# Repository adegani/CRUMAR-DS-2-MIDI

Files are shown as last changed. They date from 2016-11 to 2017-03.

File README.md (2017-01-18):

# CRUMAR-DS-2-MIDI
Add MIDI features to Crumar DS-2 Analog synth using Arduino or bare ATMega328 (with Arduino Bootloader)

This work is published under GNU/GPL.

**NOTE:** This is a WORK IN PROGRESS! Use with caution!

## Abstract
The Crumar DS-2 is a vintage made in Italy analog synth. Unfortunately, it comes without a MIDI IN/OUT capabilityes.
The goal of this project is to add the MIDI port to this wonderful peace of gear by simply substitute the original keyboard decoder board (P-431 on the DS-2 schematics) whit a new one that add MIDI capabilities.

In this repository you can find the Arduino sketch and the schematics of the DS-2_MIDI board and the connection diagram of the Crumar P-431 board.

The DS-2_MIDI board comes in two fashions:

### DS-2 MIDI IN
This simple board provides only MIDI IN to the DS-2. The schematics comes with two microcontroller footprints: one for the Arduino Nano and one for the bare ATMega328 chip.

What you **can do** with this board?
* Receive MIDI NOTE ON/OFF messages

**NOTE:** with this board, the DS-2 keyboard will be **disabled**.

In order to use this variant, please make sure to comment the line
```C
#define DS2_FULL_VARIANT
```
in **config.h**, and refer to the schematic and board *P-431_MIDI_IN_NANO* or *P-431_MIDI_IN_BARE* depending on if you use Arduino Nano or ATMega328 bare chip.

### DS-2 MIDI FULL (under development)
This advanced board provides MIDI IN and OUT to the DS-2. The schematics comes with two microcontroller footprints: one for the Arduino Nano and one for the bare ATMega328 chip.

What you **can do** with this board?
* Receive MIDI NOTE ON/OFF messages
* Send MIDI NOTE ON/OFF from DS-2 keyboard
* Send and Receive MIDI pitch shift messages (TO BE IMPLEMENTED)

**NOTE:** with this board, the DS-2 keyboard are still **usable**.

In order to use this variant, please UNcomment the line
```C
#define DS2_FULL_VARIANT
```
in **config.h**, and refer to the schematic and board *P-431_MIDI_FULL*.

## DISCLAIMER
This is not a commercial work. USE IT AT YOUR OWN RISK. I'm not responsible of any damage to your Arduino / DS-2 or your person.

### Uploading DS-2 sketch using Arduino
1. Upload Arduino ISP sketch to your Arduino
2. Open DS-2 Sketch
3. Select board -> Arduino Duemilanove or Diecimila with processor ATmega328
4. Select Programmer -> Arduino as ISP 
5. Press Upload using programmer (Ctrl+Shift+U)

If you receive a signature error, modify /home/axel/Software/arduino/hardware/tools/avr/etc/avrdude.conf, section m328p, modify the signature 0x1e 0x95 0x0F with 0x1e 0x95 0x14

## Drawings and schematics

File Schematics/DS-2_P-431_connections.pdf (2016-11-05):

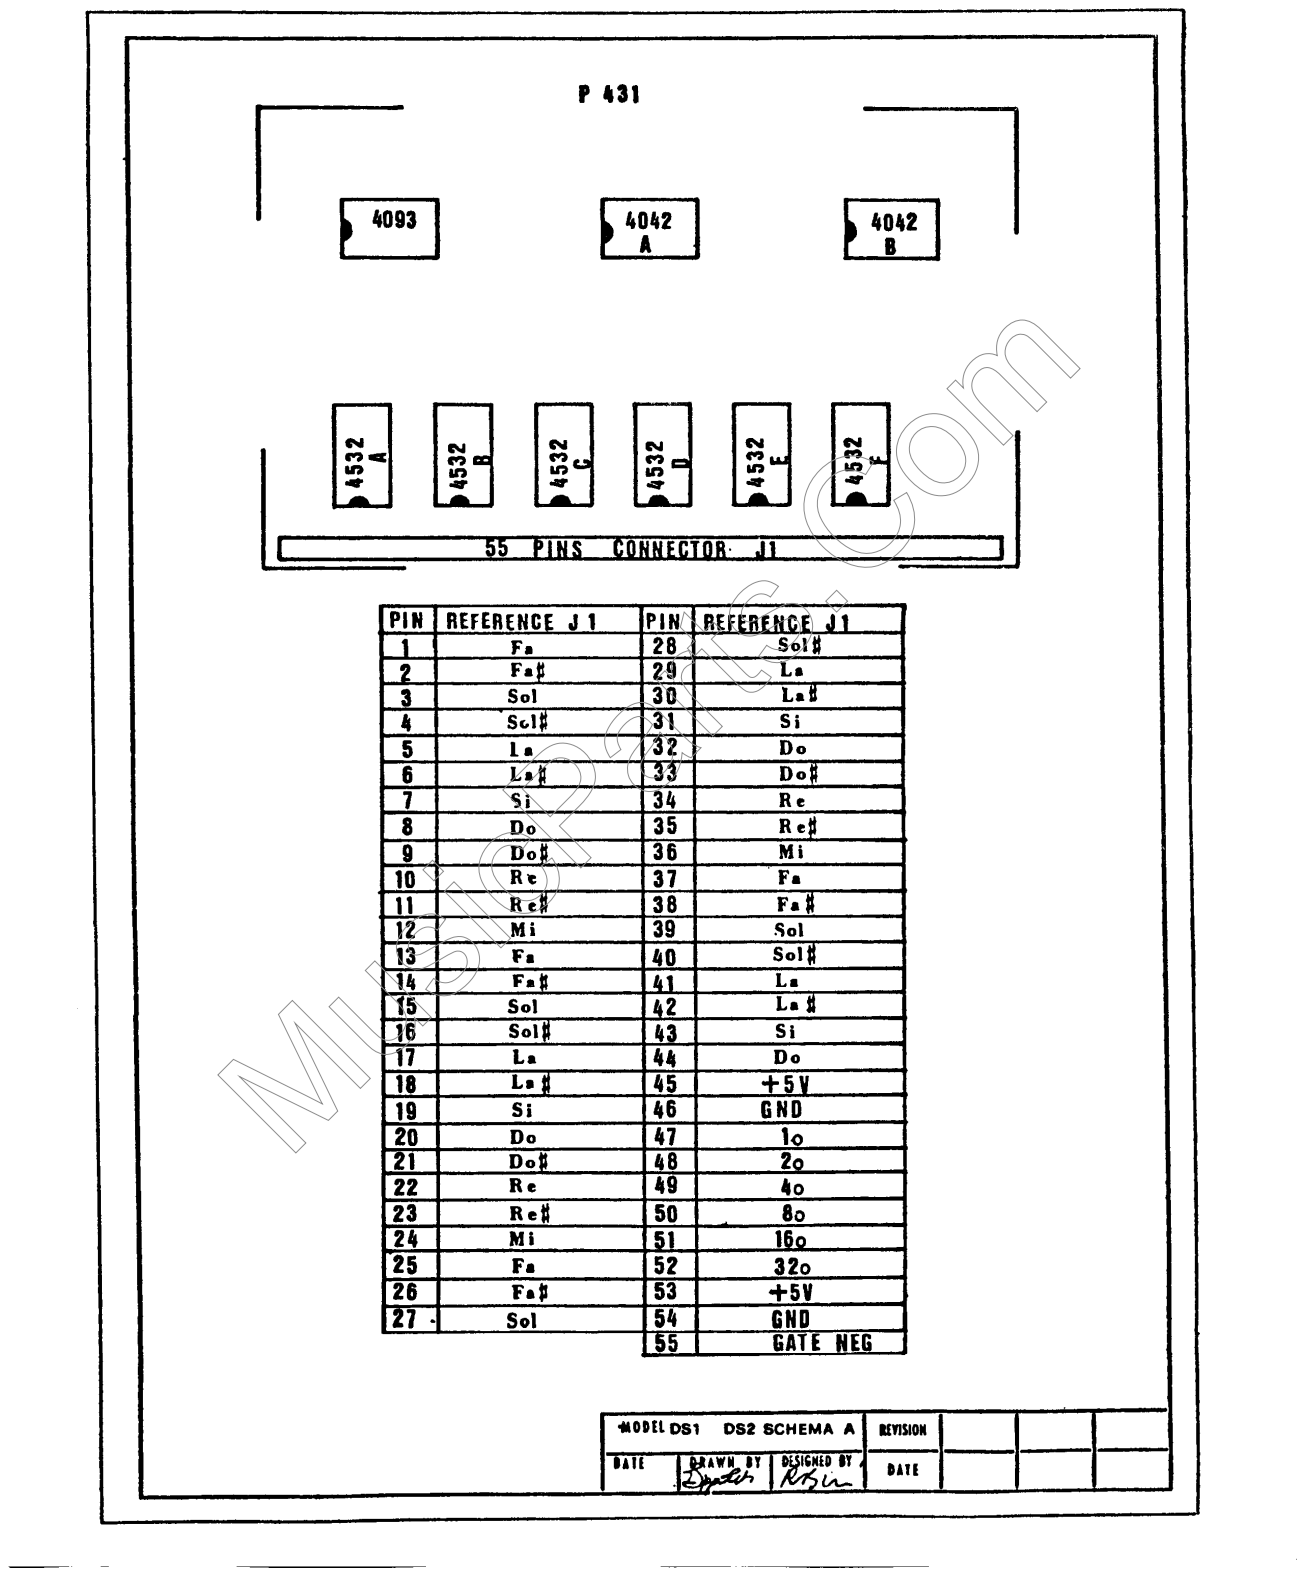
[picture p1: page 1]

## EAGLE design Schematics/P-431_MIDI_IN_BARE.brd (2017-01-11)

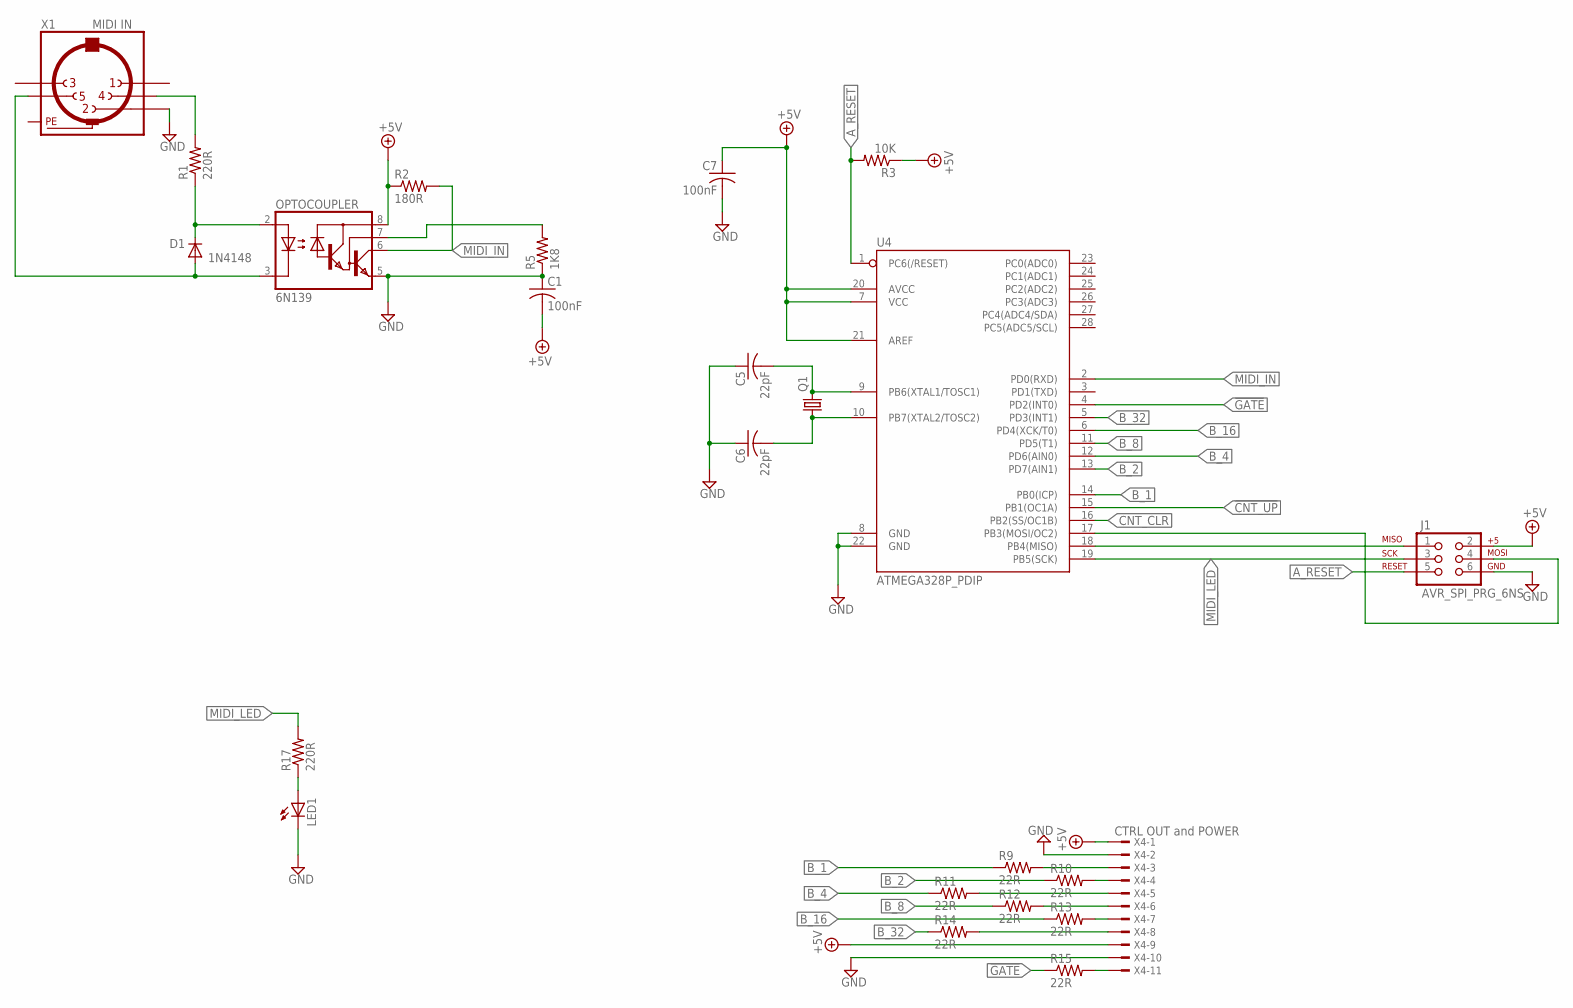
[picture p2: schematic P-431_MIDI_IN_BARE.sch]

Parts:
C1, C7: 100nF; C050-025X075
C5, C6: 22pF; C050-025X075
D1: 1N4148; DIODE-1N4148
J1: AVR_SPI_PRG_6NS; 2X3-NS
LED1: LED5MM
OPTOCOUPLER: 6N139; DIL08; MPN 6N138
Q1: CRYSTALHC49S; HC49/S
R1, R17: 220R; 0207/7
R2: 180R; 0207/7
R3: 10K; 0207/7
R5: 1K8; 0207/7
R9, R10, R11, R12, R13, R14, R15: 22R; 0207/7
U4: ATMEGA328P_PDIP; DIL28-3
X1: MIDI IN; MAB5SH
X4: CTRL OUT and POWER; TSW-111-02-S-S-RA

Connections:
!CNT_UP: U4.15 (PB1(OC1A))
!GATE: R15.1, U4.4 (PD2(INT0))
+5V: C1.2, C7.1, J1.2, OPTOCOUPLER.8 (VCC), R2.1, R3.1, U4.7 (VCC), U4.20 (AVCC), U4.21 (AREF), X4.1, X4.9
A_RESET: J1.5, R3.2, U4.1 (PC6(/RESET))
B_1: R9.1, U4.14 (PB0(ICP))
B_2: R10.1, U4.13 (PD7(AIN1))
B_4: R11.1, U4.12 (PD6(AIN0))
B_8: R12.1, U4.11 (PD5(T1))
B_16: R13.1, U4.6 (PD4(XCK/T0))
B_32: R14.1, U4.5 (PD3(INT1))
CNT_CLR: U4.16 (PB2(SS/OC1B))
GND: C1.1, C5.1, C6.1, C7.2, J1.6, LED1.K (C), OPTOCOUPLER.5 (GND), R5.1, U4.8 (GND), U4.22 (GND), X1.2, X4.2, X4.10
MIDI_IN: OPTOCOUPLER.6 (VO), R2.2, U4.2 (PD0(RXD))
MIDI_LED: J1.3, R17.2, U4.19 (PB5(SCK))
unnamed: D1.A, OPTOCOUPLER.3 (C), X1.5
unnamed: D1.C, OPTOCOUPLER.2 (A), R1.1
unnamed: R1.2, X1.4
unnamed: OPTOCOUPLER.7 (VB), R5.2
unnamed: LED1.A, R17.1
unnamed: R9.2, X4.3
unnamed: R10.2, X4.4
unnamed: R11.2, X4.5
unnamed: R12.2, X4.6
unnamed: R13.2, X4.7
unnamed: R14.2, X4.8
unnamed: R15.2, X4.11
unnamed: C5.2, Q1.2, U4.9 (PB6(XTAL1/TOSC1))
unnamed: C6.2, Q1.1, U4.10 (PB7(XTAL2/TOSC2))
PE: X1.PE, X1.PE@ (PE)
POT_DI: J1.1, U4.18 (PB4(MISO))
POT_SCK: J1.4, U4.17 (PB3(MOSI/OC2))

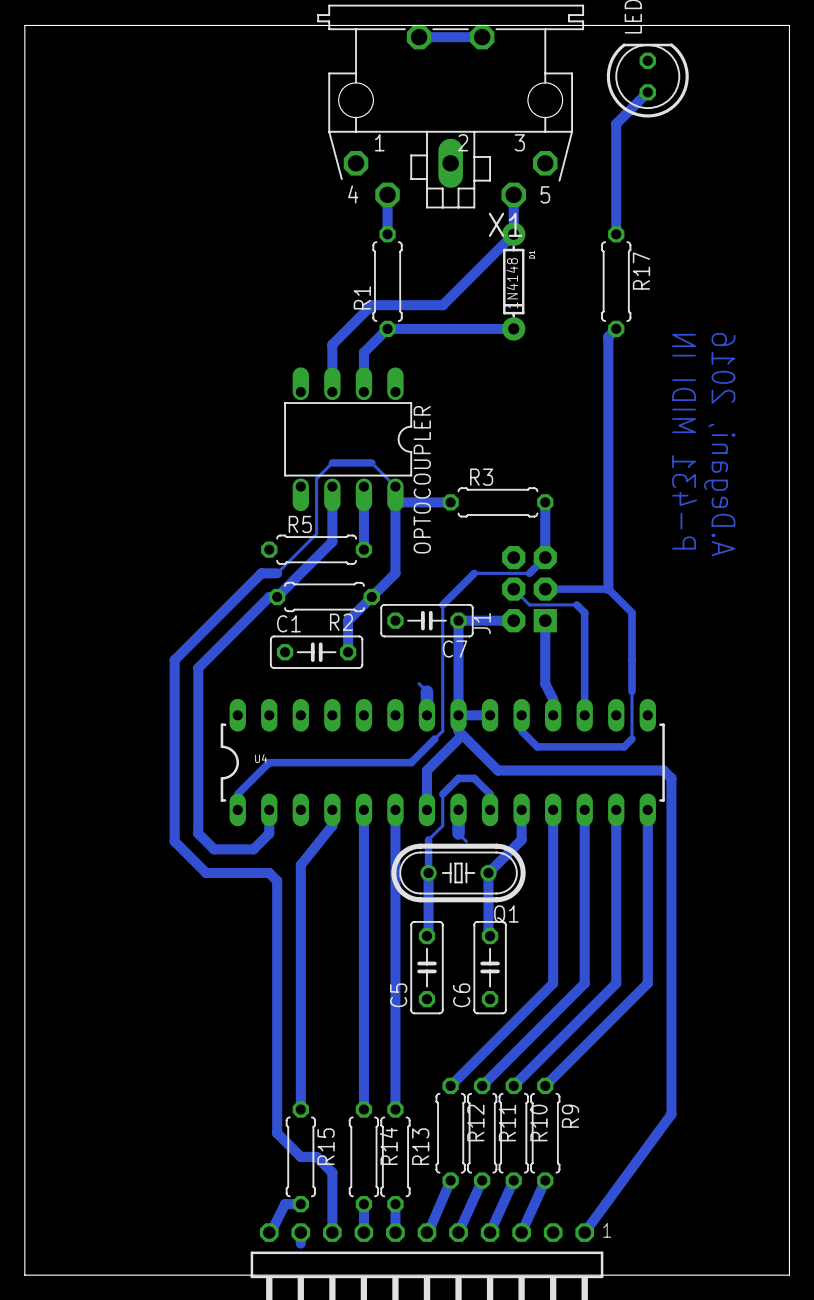
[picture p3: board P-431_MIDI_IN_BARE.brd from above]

Board: 2 copper layers, 61.6 x 100.6 mm, 24 parts (0 on the bottom side), 29 nets.

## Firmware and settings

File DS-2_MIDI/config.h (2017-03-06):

/* config.h
 *  Config and Arduino pin names
 *  Author: Alessio Degani, 2016 <alessio.degani@gmail.com>
 */

#ifndef DS2_CONFIG_H
#define DS2_CONFIG_H

// General Config
//#define DS2_FULL_VARIANT // Uncomment to use FULL variant instead of NANO

// Note priority [LAST|HIGHER|LOWER]
#define PLAY_MODE_MIDI LAST

// Gate mode [GATE_SINGLE|GATE_RETRIGGER]
#define DEFAULT_GATE_MODE GATE_SINGLE

#define NOTE_TRANSPOSE_SEMITONE 0

// Default MIDI channel
#define DEFAULT_MIDI_CH 0

// Control Change for P431-MIDI
#define DS2_PLAY_MODE      0x66
#define DS2_GATE_MODE      0x67
#define DS2_SET_CHANNEL    0x68
#define DS2_HOLD_NOTE      0x69
#define DS2_ARP_MODE       0x6A
#define DS2_TRANSPOSE_SEMI 0x6B

// Configure the ATMega328 pin names

// OUTPUTS to CRUMAR
#define DS2_GATE_NEG  2
#define DS2_32o       3
#define DS2_16o       4
#define DS2_8o        5
#define DS2_4o        6
#define DS2_2o        7
#define DS2_1o        8

// DS-2 MIDI NOTE range
#define DS2_LOWER_NOTE  41
#define DS2_HIGHER_NOTE 84

// MIDI ports and LED
#define MIDI_LED      13
#define MIDI_OUT      0
#define MIDI_IN       1

// ----- NOT USED IN DS-2 MIDI IN only VERSION -----

// COUNTER
#define COUNT_UP_NEG  9
#define COUNT_CLR     10

// DIGIPOT --> OUT (pitch shifter)
#define POT_SCK       11
#define POT_DI        12

// ANALOG POT --> READ (pitch shifter)
#define PS_POT1       A5
#define PS_POT2       A4
#define PS_POT3       A3

// MUX READ (INPUT from CRUMAR keyboard)
#define K0            A0
#define K1            A1
#define K2            A2

#endif // DS2_CONFIG_H

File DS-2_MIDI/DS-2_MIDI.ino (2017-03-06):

/* DS-2 MIDI IN NANO
 *  Add MIDI input capabilities to CRUMAR DS-2
 *  Author: Alessio Degani, 2016 <alessio.degani@gmail.com>
 */

#include "config.h"
#include "noteList.h"
#include "midiDefs.h"
#include "midiFSM.h"

midiFSM_t midiFSM;

enum gate_mode_e { GATE_SINGLE, GATE_RETRIGGER };
gate_mode_e gate_mode = DEFAULT_GATE_MODE;

byte midiChannel = DEFAULT_MIDI_CH;

MidiNoteList<16> midiNotes;

byte lastNote;
byte midiByte;

// Note transposition
int transposeSemitone = NOTE_TRANSPOSE_SEMITONE;

// MIDI led activity, led_status is for pesistence of the led, otherwise, the led will stay on too few
bool          midi_led_status         = 0;
unsigned int  midi_led_duration_loops = 3;
unsigned int  midi_led_timer          = 0;

void playNote( byte note, byte velocity ){

  // TODO: forse questo ciclo adesso si può eliminare
  // A note off -> close the gate 
  if ( (velocity == 0) || (note < DS2_LOWER_NOTE) || (note > DS2_HIGHER_NOTE) ) {
    digitalWrite( DS2_GATE_NEG, HIGH );
    return;
  }

  note = note + transposeSemitone;

  if (( note >= DS2_LOWER_NOTE ) && ( note <= DS2_HIGHER_NOTE )) {
    note = note - DS2_LOWER_NOTE;

    if ( (gate_mode == GATE_RETRIGGER) && (lastNote != note) ) {
      digitalWrite( DS2_GATE_NEG, HIGH );
    }

    ( (note & 32) == 32 ) ? digitalWrite(DS2_32o, HIGH): digitalWrite(DS2_32o, LOW);
    ( (note & 16) == 16 ) ? digitalWrite(DS2_16o, HIGH): digitalWrite(DS2_16o, LOW);
    ( (note & 8)  == 8 )  ? digitalWrite(DS2_8o, HIGH): digitalWrite(DS2_8o, LOW);
    ( (note & 4)  == 4 )  ? digitalWrite(DS2_4o, HIGH): digitalWrite(DS2_4o, LOW);
    ( (note & 2)  == 2 )  ? digitalWrite(DS2_2o, HIGH): digitalWrite(DS2_2o, LOW);
    ( (note & 1)  == 1 )  ? digitalWrite(DS2_1o, HIGH): digitalWrite(DS2_1o, LOW);
    digitalWrite( DS2_GATE_NEG, LOW );
    lastNote = note;
  }

}

void handleCC(midiFSM_event_t *e){
  switch (e->data1){
    case MIDI_ALL_SOUND_OFF:
    case MIDI_ALL_NOTE_OFF:
    case MIDI_RESET_CTRL:
    case MIDI_RESET_ALL:
    midiNotes.reset();
  }
}

void handleMessage(midiFSM_event_t *e){
  switch (e->status){
    case MIDI_NOTE_ON:
      if (e->data2 == 0){
        midiNotes.remove(e->data1);
      } else {
        const bool firstNote = midiNotes.empty();
        midiNotes.add(MidiNote(e->data1, e->data2));
      }
      break;
    case MIDI_NOTE_OFF:
      midiNotes.remove(e->data1);
      break;
    case MIDI_CONTROL_CHANGE:
      handleCC(e);
      break;

  }
}
void handleSysex( uint8_t byte ){}
void handleRealTimeMessage( uint8_t byte ){}

void setup() {
  lastNote = 0;

  // Setup decoded output port for DS-2
  pinMode( DS2_GATE_NEG, OUTPUT );
  pinMode( DS2_1o,       OUTPUT );
  pinMode( DS2_2o,       OUTPUT );
  pinMode( DS2_4o,       OUTPUT );
  pinMode( DS2_8o,       OUTPUT );
  pinMode( DS2_16o,      OUTPUT );
  pinMode( DS2_32o,      OUTPUT );
  pinMode( MIDI_LED,     OUTPUT );

  // Default GATE for DS-2 is HIGH
  digitalWrite( DS2_GATE_NEG, HIGH ); // DS-2 has a NOT-GATE

  // Serial port (MIDI), default baud rate 31250
  Serial.begin( MIDI_RATE );

  // Initialize the note list
  midiFSM_init(&midiFSM, &handleMessage, &handleSysex, &handleRealTimeMessage);

}

void sequencer( ){
  // If there are note to play or send via MIDI, this is the right moment to do that!
  byte currentNote = 0;
  midiNotes.getLast(currentNote);
  
  playNote( currentNote, 127 );

  #ifdef DS2_FULL_VARIANT
  // TODO: if FULL board, sequence the MIDI OUT notes
  #endif
}

void loop() {

  #ifdef DS2_FULL_VARIANT
  // TODO: if FULL board, read the DS-2 keyboard
  #endif

  // MIDI activity led mini FSM
  if ( midi_led_status == 1 ){
    midi_led_timer++;
    if ( midi_led_timer > midi_led_duration_loops ){
      midi_led_status = 0;
      midi_led_timer  = 0;
    }
  }


  if (Serial.available() > 0) {
    // A MIDI message is arrived

    // start MIDI led activity mini FSM
    midi_led_timer  = 0;
    midi_led_status = 1;
    
    midiByte = Serial.read();
    midiFSM_handleByte(&midiFSM,midiByte );

  }

  // Sequence the note received
  sequencer(  );

  digitalWrite( MIDI_LED, midi_led_status );

}

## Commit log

2016-11-05 First commit: preliminary sketch and P-431 schematics
2016-11-05 Added first revision of simple MIDI in schematics based on Arduino/Arduino NANO
    [P-431_MIDI_IN_NANO.brd, P-431_MIDI_IN_NANO.sch]
2016-11-06 Added pin config include
2016-11-07 Added MIDI activity LED and MIDI channel filter
2017-01-11 Added reset pullup resistor and fixed resistors value for optocoupler
    [P-431_MIDI_IN_BARE.brd, P-431_MIDI_IN_BARE.sch]
2017-01-20 Renamed MIDI FSM state names and added some persistence for the MIDI actovity LED
2017-01-24 Changed noteList to a more friendly and effective linked list and fixed note priority bug. Added Gate mode
    [DS-2_MIDI.ino, config.h]
2017-01-24 Added CC and pitch Wheel support plus some minor bug fix
    [DS-2_MIDI.ino]
2017-01-24 Added a GUI written in PureData for P431-MIDI board config via MIDI CCs
2017-02-08 Fixed: all note/sound off and running status bugs
    [DS-2_MIDI.ino]
2017-03-06 New MIDI fsm, optmization and bug fixes
    [DS-2_MIDI.ino]

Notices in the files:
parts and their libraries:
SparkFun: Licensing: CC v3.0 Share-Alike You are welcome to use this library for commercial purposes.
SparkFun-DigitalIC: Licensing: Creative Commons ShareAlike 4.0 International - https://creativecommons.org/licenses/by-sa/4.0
